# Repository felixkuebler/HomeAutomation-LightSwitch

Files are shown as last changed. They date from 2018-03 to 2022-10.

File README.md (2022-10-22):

# Introduction
Due to the growing demand of iot devices for home automation this project presents an cheap, easy to use and "open source" alternative to brand Products such as Phillips Hue. Based on the ESP8266-12E, a small WiFi enabled chipset, these devices can be retrofitted in a variety of devices such as light switches, motor controllers and more.

Each home automation node will access your local wifi network and is configurable through a webpage hosted locally on the device itsself. Your network needs to provide a [mqtt](https://pagefault.blog/2017/03/02/using-local-mqtt-broker-for-cloud-and-interprocess-communication/) broker to enable communication between nodes thus enabling its full functionality. An easy to use webinterface as well as a mqtt broker is provided by [Openhab](https://www.openhab.org/).

# Light Switch
The light switch module is an small embedded device that can be integrated in your 220 VAC power grid without any special adaptations. Powered by the [HLK-PM01](http://www.hlktech.net/product_detail.php?ProId=54) this module provides two digital inputs as well as two solid state relay outputs. Each input and output can be assigned and modified individually via the local web interface. Due to its small form factor it can easily be fitted behind any flush-mounted box with a min. depth of 41mm.

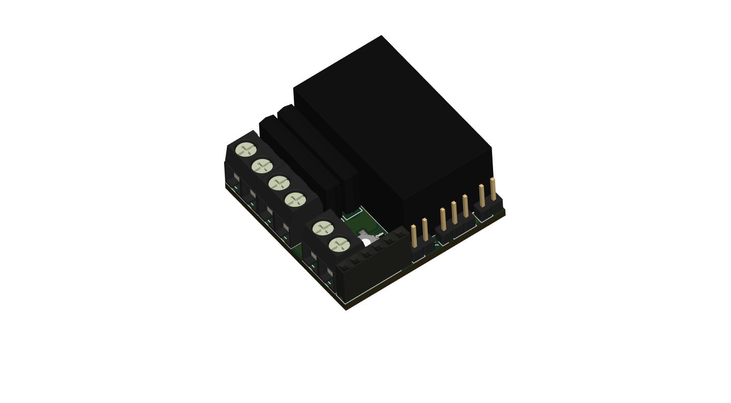
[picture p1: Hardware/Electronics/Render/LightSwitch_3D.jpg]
[light switch render]

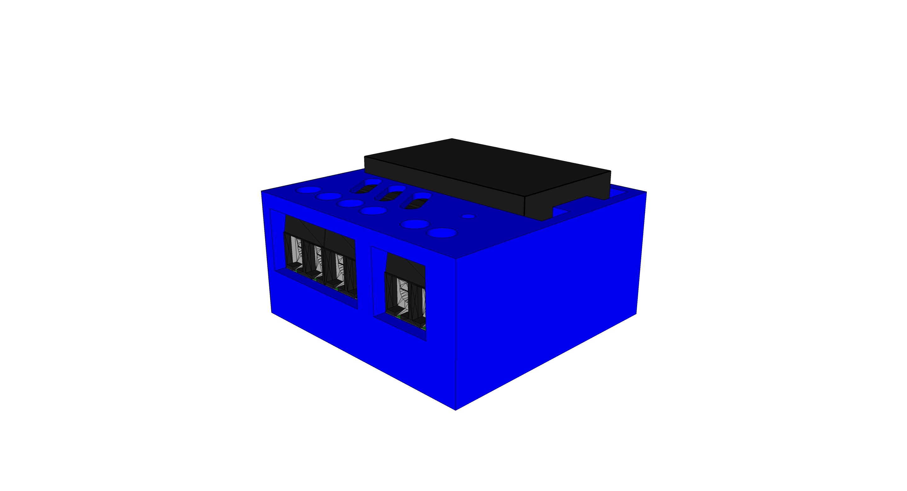
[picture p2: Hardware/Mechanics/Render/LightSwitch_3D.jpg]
[light switch render]


The current versions can be found here:
* [Version 1.0](../../tree/Version1.0)

# License
This work is property of Felix Kübler and is licensed under the
<a rel="license" href="http://creativecommons.org/licenses/by-nc/4.0/">Creative Commons Attribution-NonCommercial 4.0 International License</a>.

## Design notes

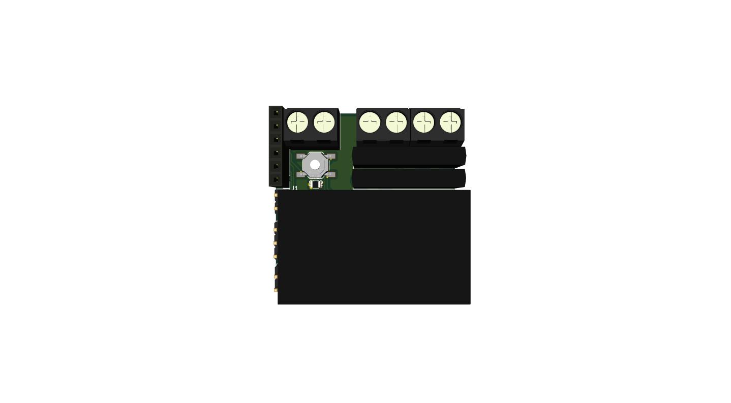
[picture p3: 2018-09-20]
Hardware/Electronics/Render/LightSwitch_top.jpg

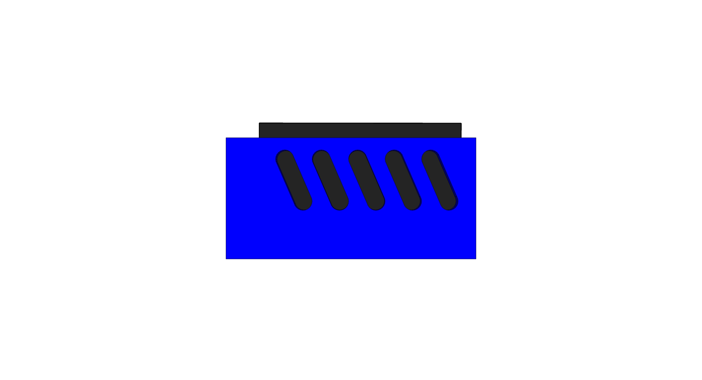
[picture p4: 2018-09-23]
Hardware/Mechanics/Render/LightSwitch_Back.jpg

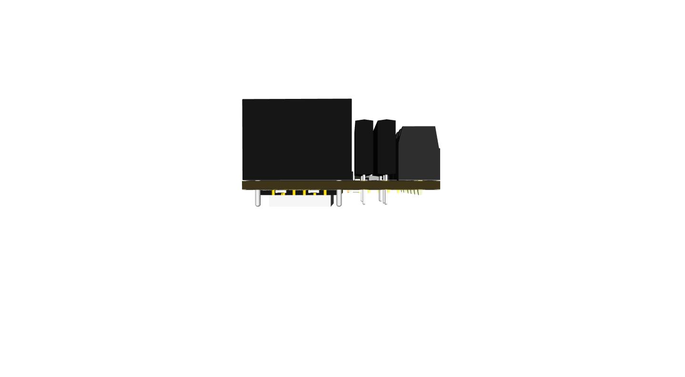
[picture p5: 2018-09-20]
Hardware/Electronics/Render/LightSwitch_right.jpg

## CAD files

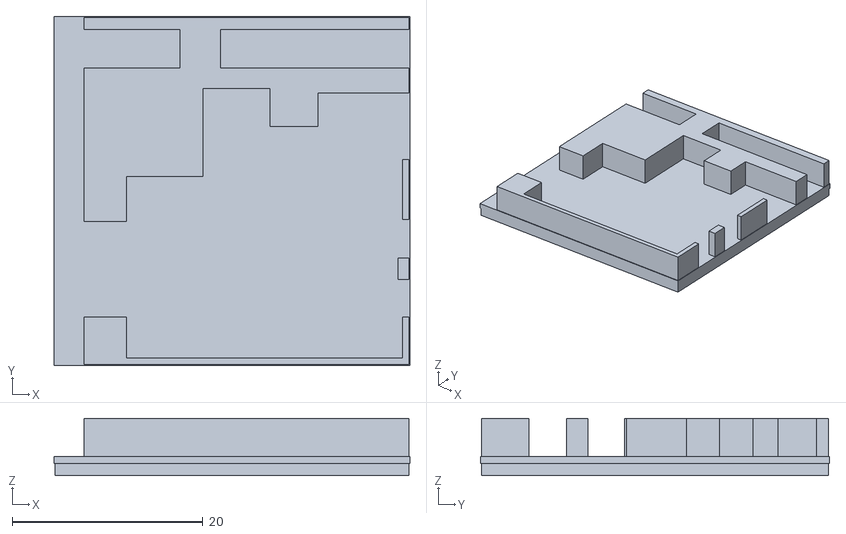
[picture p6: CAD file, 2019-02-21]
Hardware/Mechanics/PrintParts/HousingBottom.stl
37.3 x 36.6 x 6.01

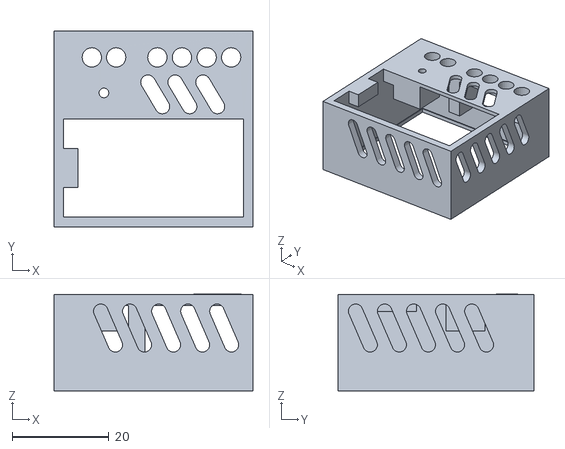
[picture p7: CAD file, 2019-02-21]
Hardware/Mechanics/PrintParts/HousingTop.stl
41.1 x 40.4 x 19.9

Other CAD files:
Hardware/Mechanics/CAD/LightSwitch.skp
Hardware/TestAssembly/CAD/TestAssembly.skp

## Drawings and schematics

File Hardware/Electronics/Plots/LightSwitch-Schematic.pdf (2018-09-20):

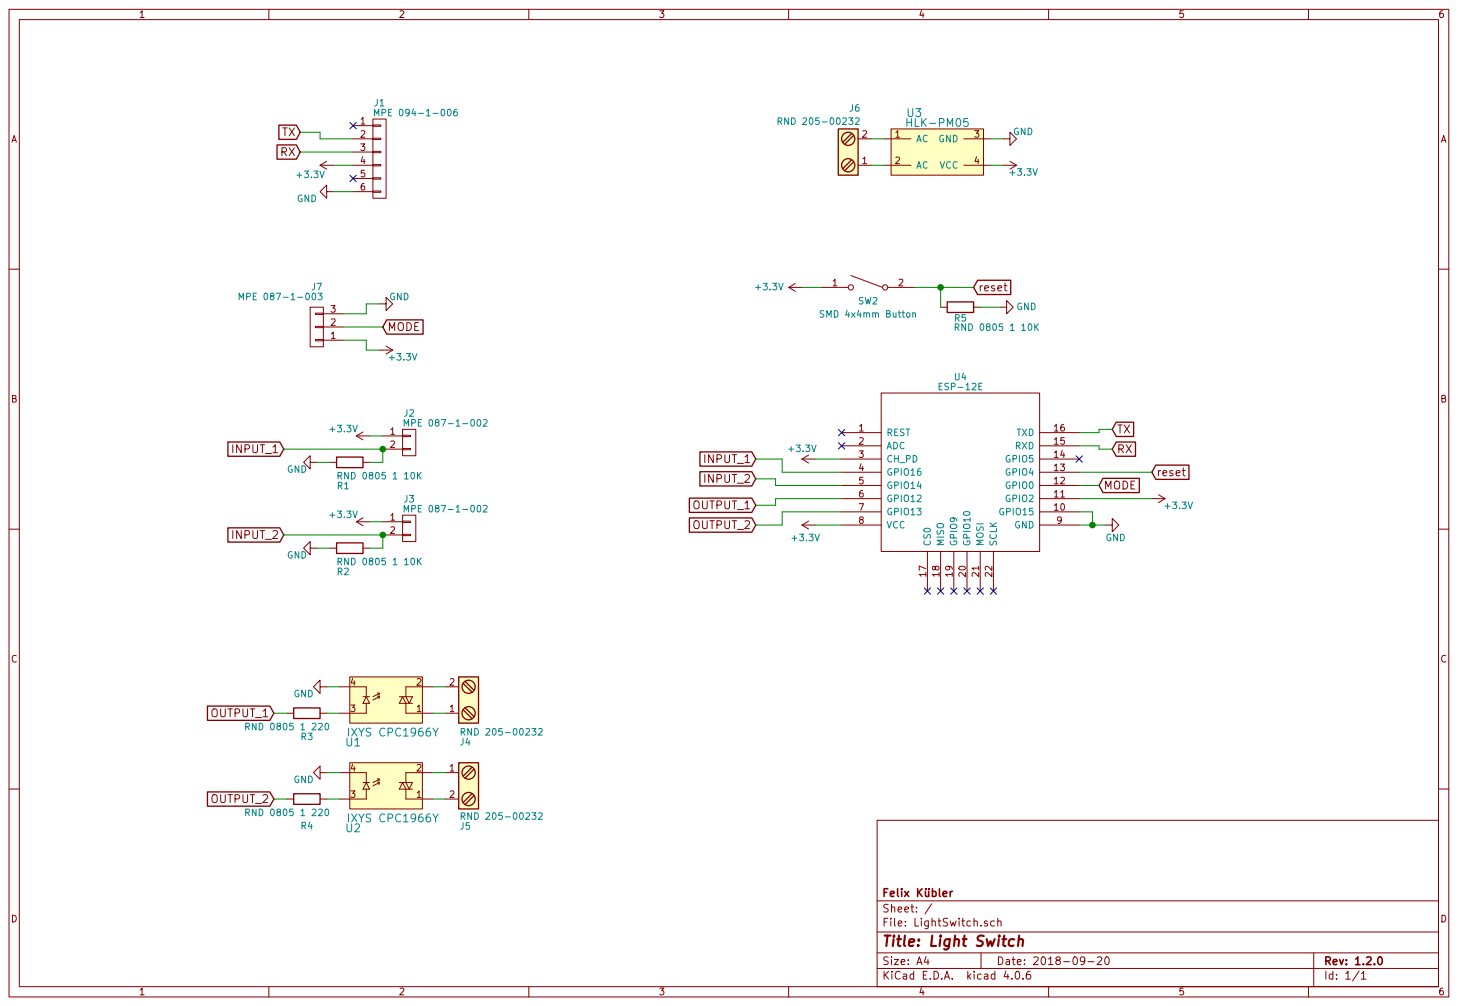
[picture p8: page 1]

File: LightSwitch.sch Sheet: / Felix Kübler

Id: 1/1 Title: Light Switch

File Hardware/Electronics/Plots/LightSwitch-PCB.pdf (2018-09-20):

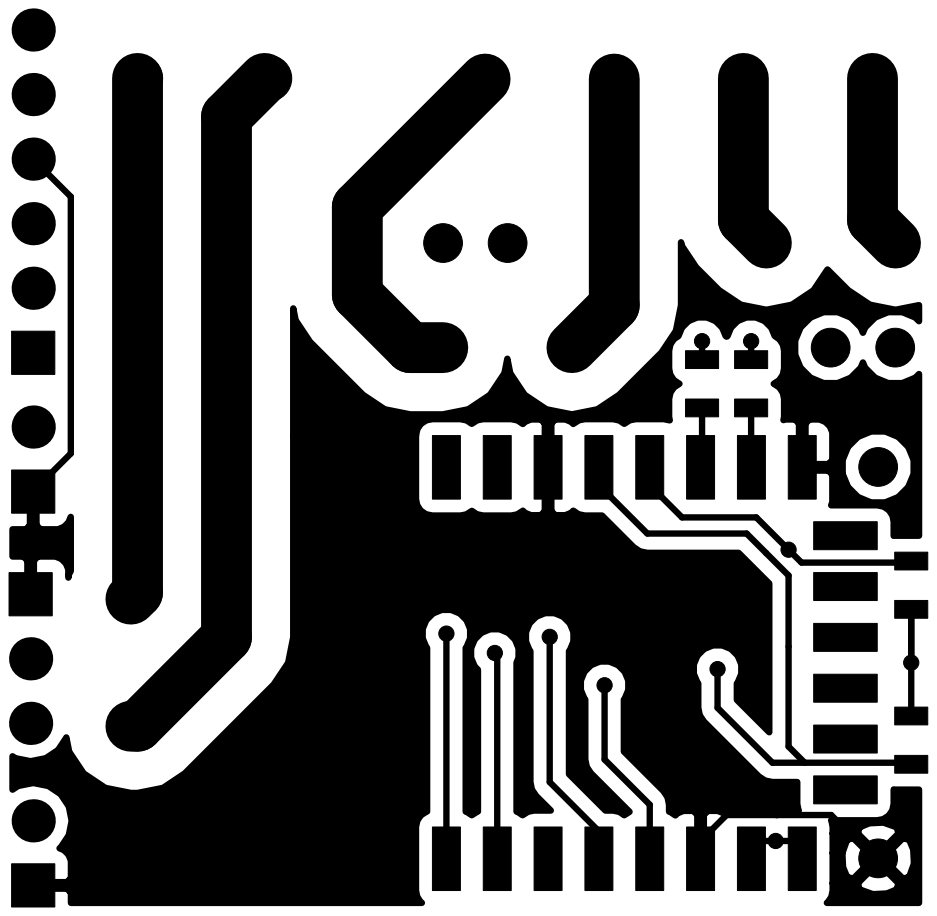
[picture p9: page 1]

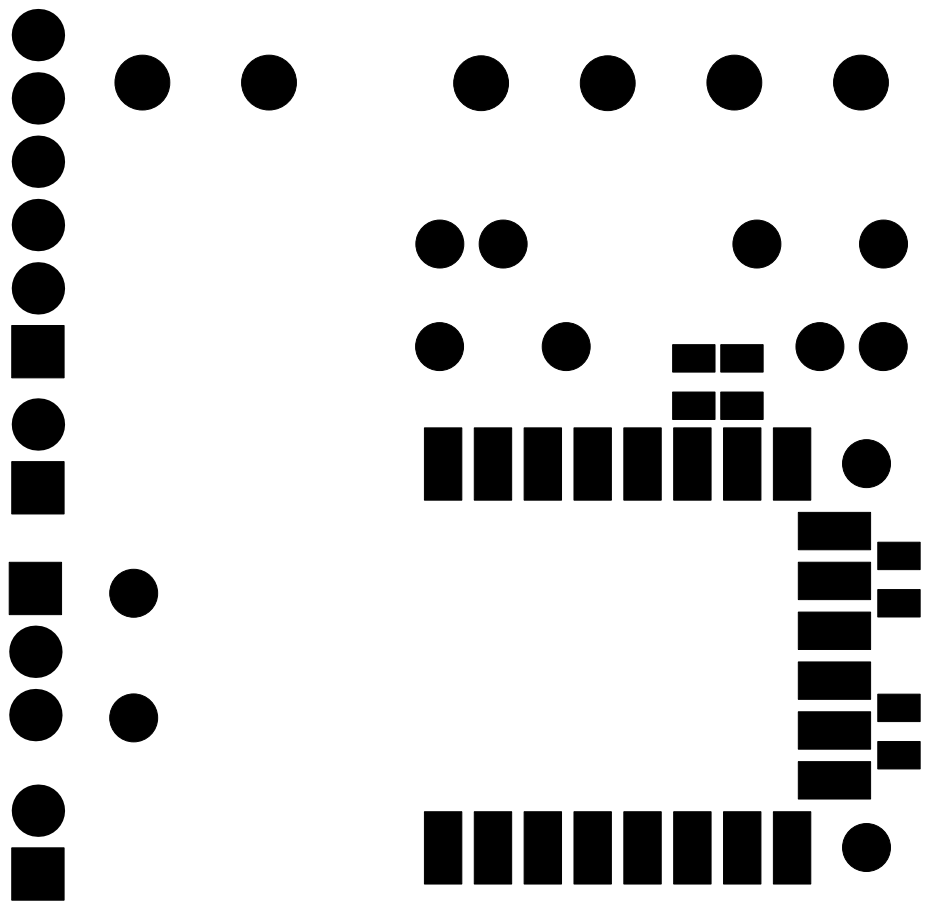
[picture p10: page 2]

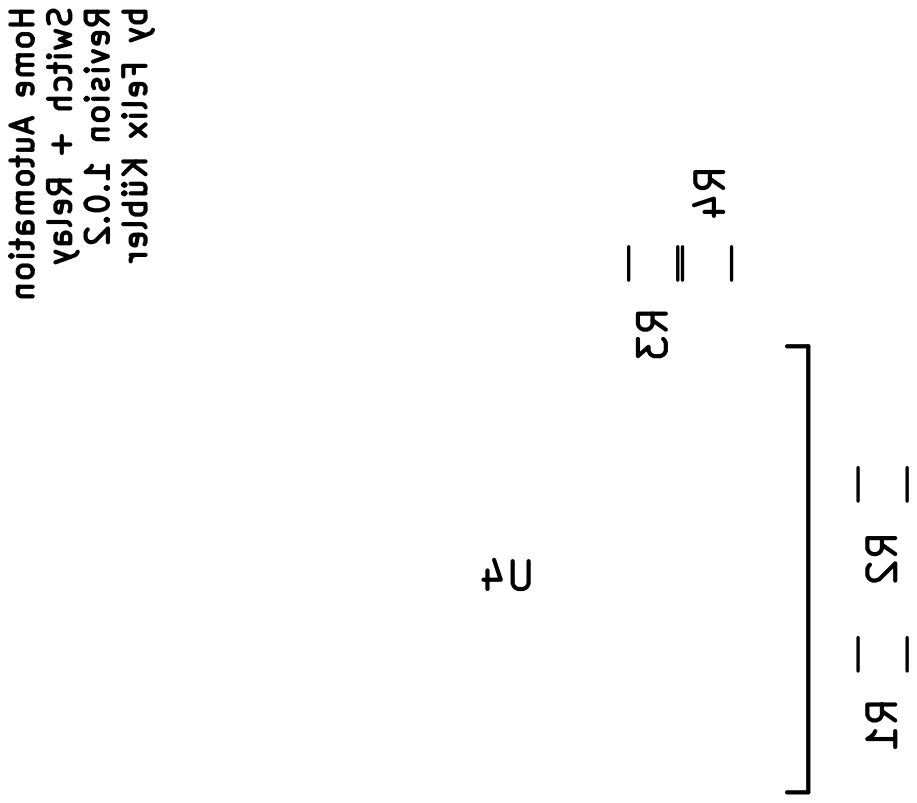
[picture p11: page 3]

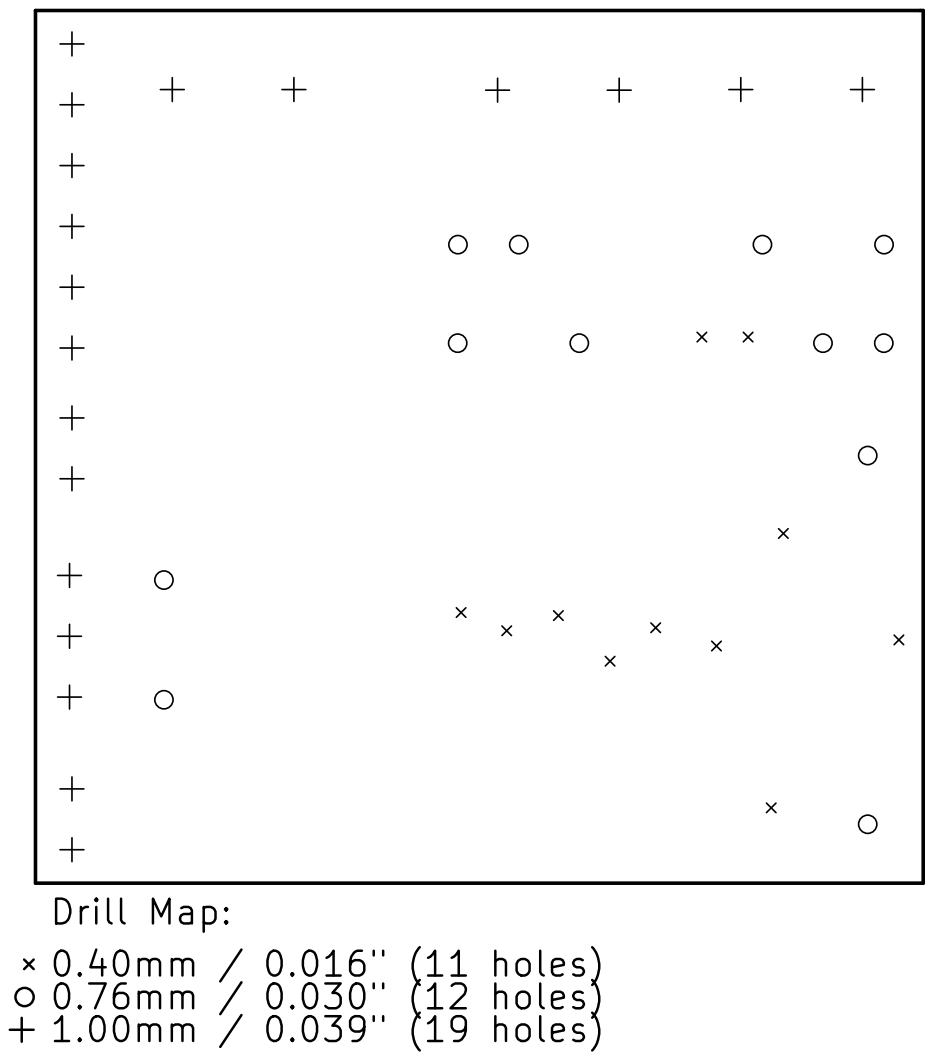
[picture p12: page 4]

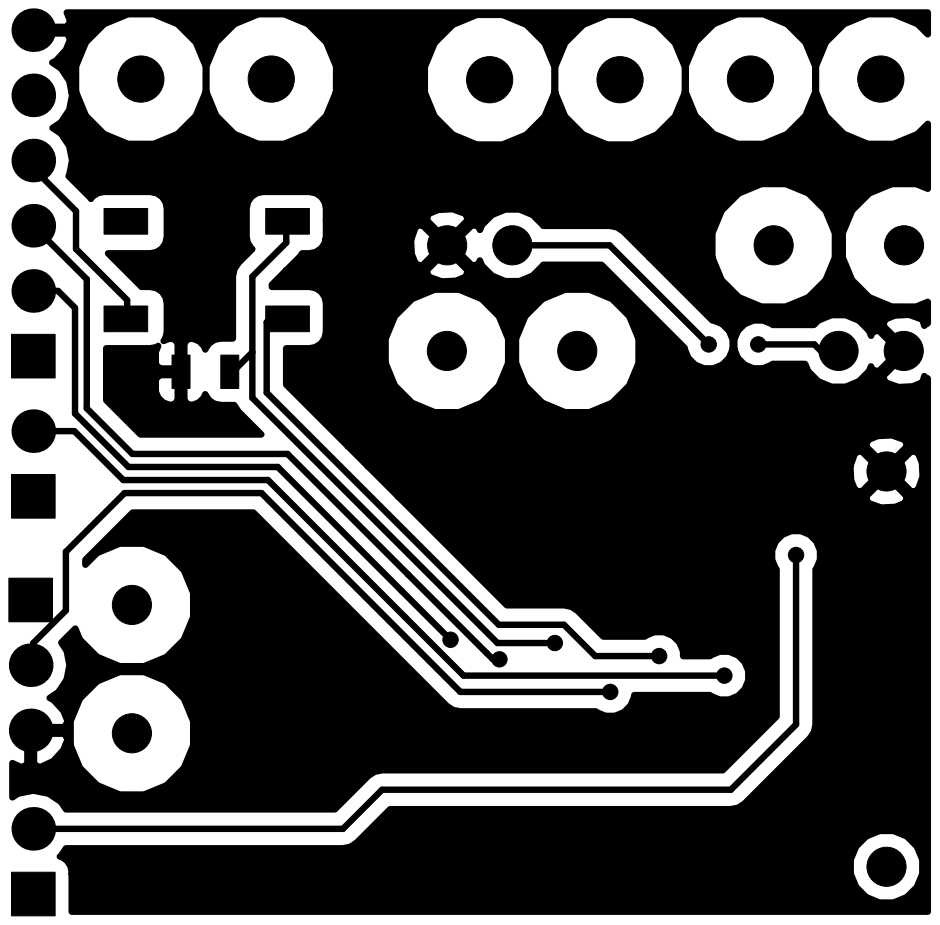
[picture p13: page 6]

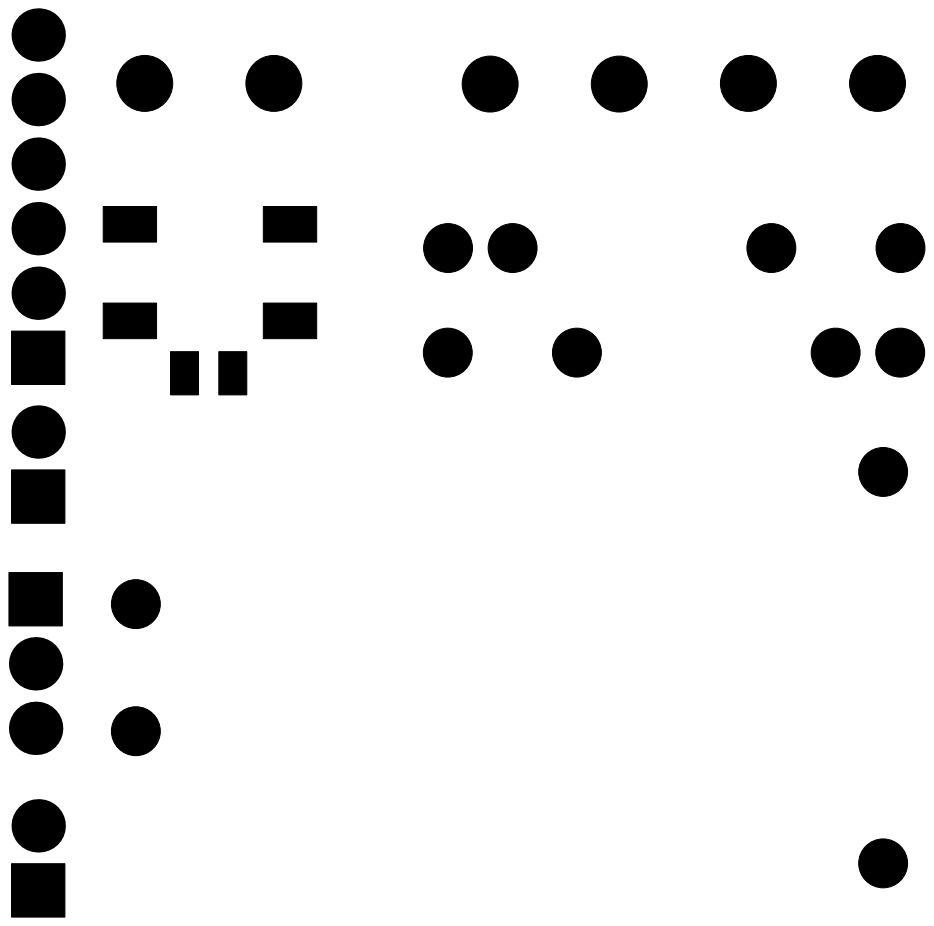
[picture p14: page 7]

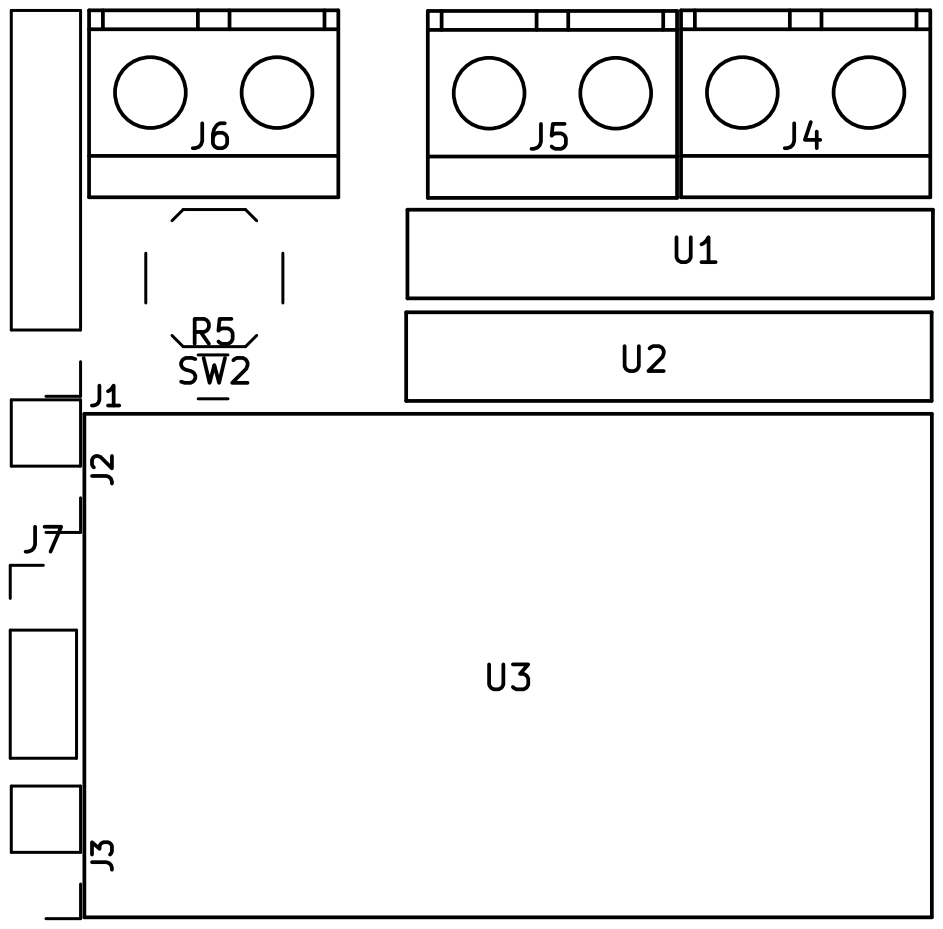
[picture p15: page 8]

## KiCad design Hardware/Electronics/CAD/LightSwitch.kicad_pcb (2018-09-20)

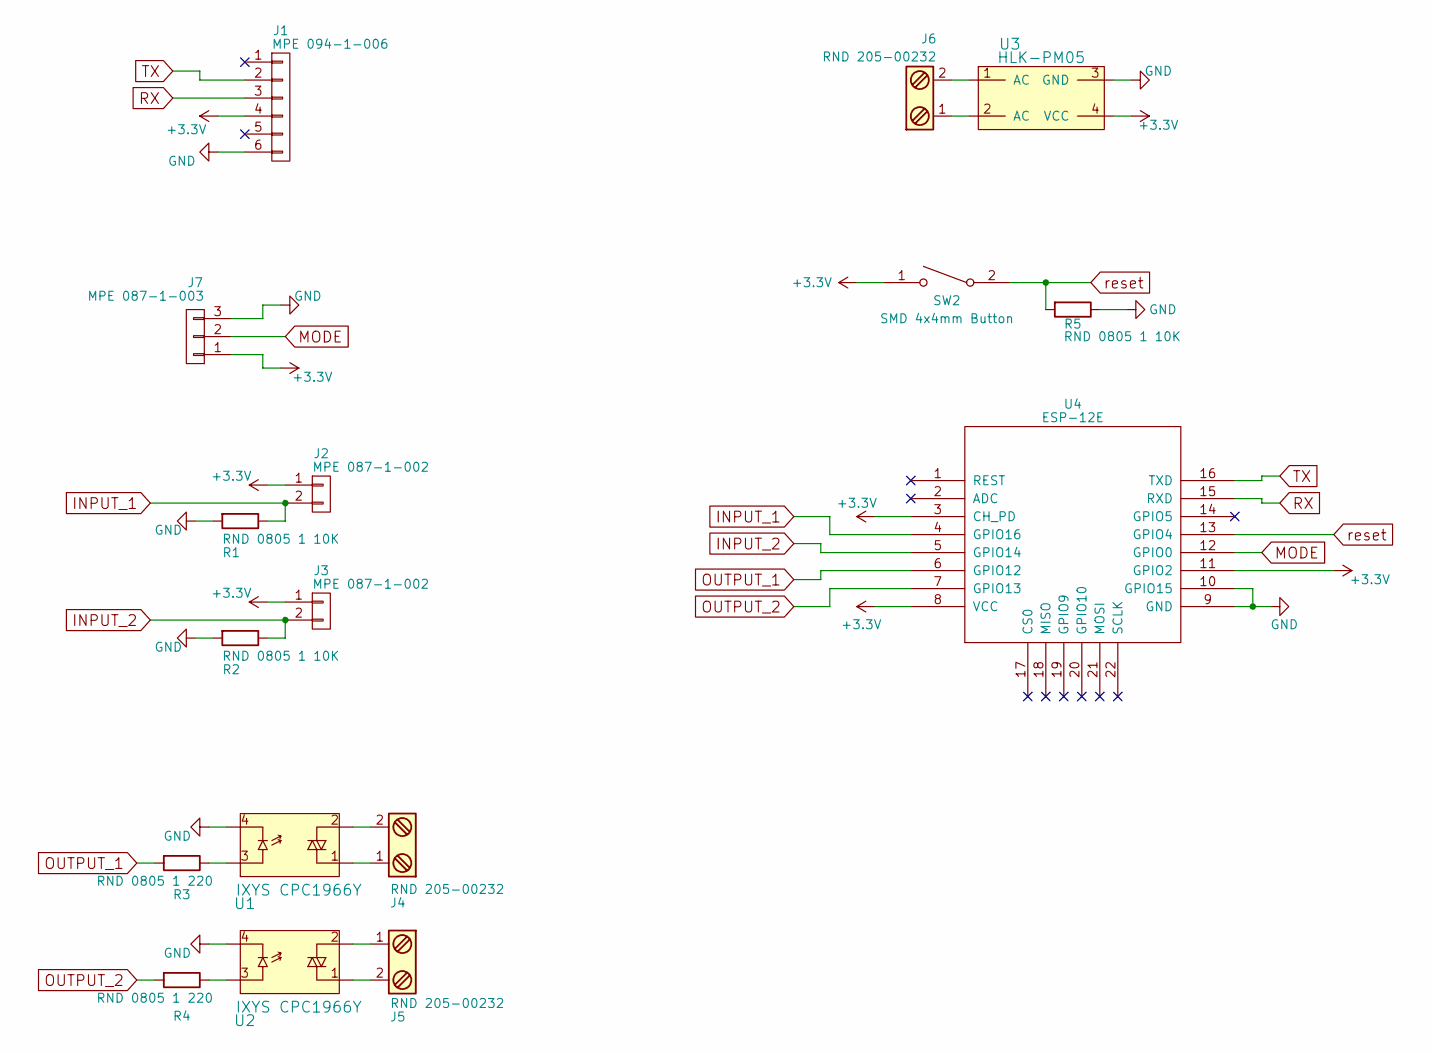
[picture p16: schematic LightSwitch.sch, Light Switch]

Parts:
J1: MPE 094-1-006; Pin_Header_Straight_1x06_Pitch2.54mm
J2, J3: MPE 087-1-002; Pin_Header_Straight_1x02_Pitch2.54mm
J4, J5, J6: RND 205-00232; Terminal_1x2_2.54mm
J7: MPE 087-1-003; Pin_Header_Straight_1x03_Pitch2.54mm
R1, R2, R5: RND 0805 1 10K; R_0805
R3, R4: RND 0805 1 220; R_0805
SW2: SMD 4x4mm Button; SW_SPST_TL3342
U1, U2: IXYS CPC1966Y; CPC1966Y
U3: HLK-PM05; HLK-PM01
U4: ESP-12E; ESP-12E_SMD

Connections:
+3V3: J1.4, J2.1, J3.1, J7.1, SW2.1, U3.4 (VCC), U4.3 (CH_PD), U4.8 (VCC), U4.11 (GPIO2)
GND: J1.6, J7.3, R1.2, R2.2, R5.1, U1.4, U2.4, U3.3 (GND), U4.9 (GND), U4.10 (GPIO15)
INPUT_1: J2.2, R1.1, U4.4 (GPIO16)
INPUT_2: J3.2, R2.1, U4.5 (GPIO14)
MODE: J7.2, U4.12 (GPIO0)
unnamed: J4.1, U1.1
unnamed: J4.2, U1.2
unnamed: J5.1, U2.2
unnamed: J5.2, U2.1
unnamed: J6.1, U3.2 (AC)
unnamed: J6.2, U3.1 (AC)
unnamed: R3.1, U1.3
unnamed: R4.1, U2.3
OUTPUT_1: R3.2, U4.6 (GPIO12)
OUTPUT_2: R4.2, U4.7 (GPIO13)
RX: J1.3, U4.15 (RXD)
TX: J1.2, U4.16 (TXD)
reset: R5.2, SW2.2, U4.13 (GPIO4)

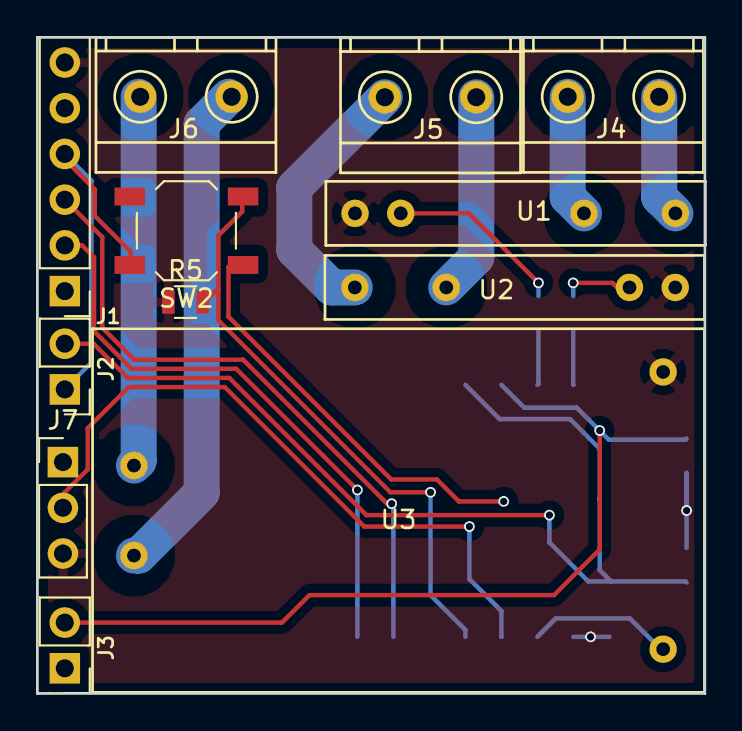
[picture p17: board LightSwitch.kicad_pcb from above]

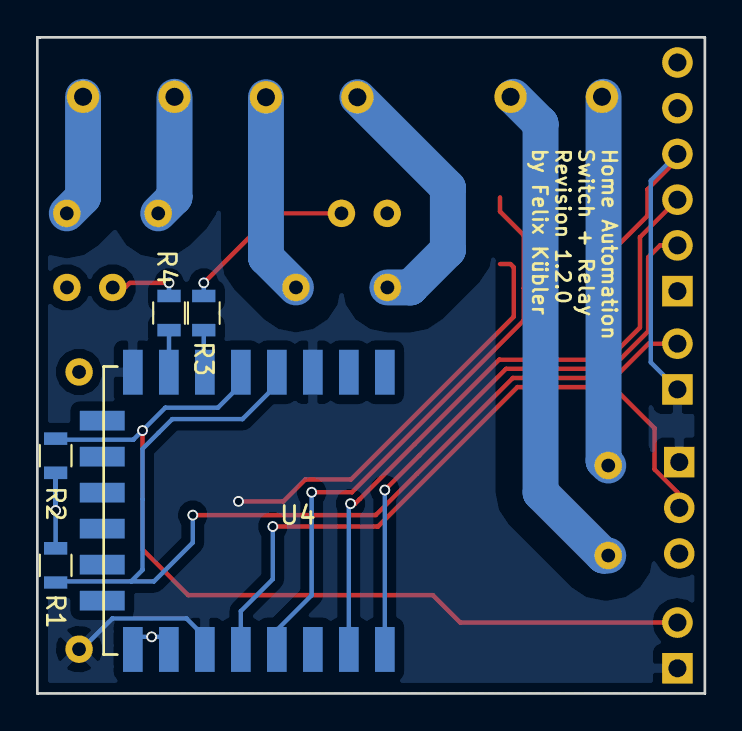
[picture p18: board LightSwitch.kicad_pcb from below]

Board: 2 copper layers, 37.1 x 36.4 mm, 17 parts (5 on the bottom side), 18 nets.

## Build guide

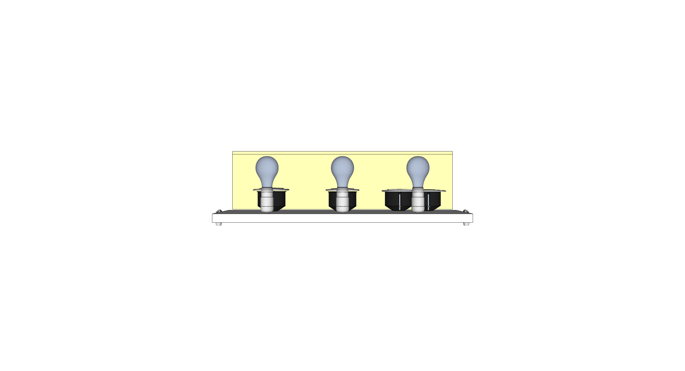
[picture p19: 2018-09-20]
Hardware/TestAssembly/Render/TestAssembly_front.jpg

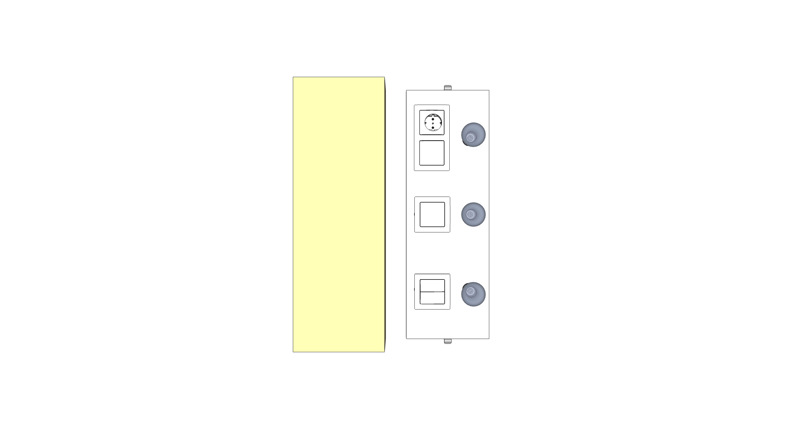
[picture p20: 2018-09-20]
Hardware/TestAssembly/Render/TestAssembly_top.jpg

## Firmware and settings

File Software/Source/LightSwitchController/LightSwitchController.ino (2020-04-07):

/**@file Source.ino**/
 
#include <map>
#include <vector>

#include <ESP8266WiFi.h>
#include <DNSServer.h>
#include <ESP8266WebServer.h>
#include <WiFiClient.h> 
#include <PubSubClient.h>
#include <ESP8266HTTPUpdateServer.h>
#include <EEPROM.h>

#include "utils.h"
#include "io_utils.h"
#include "wifi_utils.h"
#include "eeprom_utils.h"
#include "web_interface.h"


io_list input_list;
io_list output_list;

wifi_obj wifi_info;

short int reset_pin;


DNSServer dnsServer;
ESP8266WebServer wifiServer(80);
WiFiClient wifiClient;
ESP8266HTTPUpdateServer wifiUpdater;
PubSubClient client(wifiClient);


CONFIG setup_type = default_config;
bool network_available = false;



/*
 * this function is called when a html request was send to the local html server
 */
void htmlHandleRequest() 
{

  //webrequest for output
  for (io_list::iterator it=output_list.begin(); it!=output_list.end(); ++it)
  {
    //get name of output
    String val = wifiServer.arg(it->second.topic);
    //check if message is not empty
    if(val.length()>0)
    {
      Serial.print("Setting " + it->second.topic + " to ");

      int trigger_value = -1;
      
      //set changes
      if(strcmp(val.c_str(),"toggle") == 0) 
      {
        if(it->second.state == HIGH)
        {
          trigger_value = LOW;
          Serial.println("OFF");
        }
        else
        {
          trigger_value = HIGH;
          Serial.println("ON");
        }
      }
      else if(strcmp(val.c_str(),"on") == 0) 
      {
        trigger_value = HIGH;
        Serial.println("ON");
      }
      else if(strcmp(val.c_str(),"off") == 0) 
      {
        trigger_value = LOW;
        Serial.println("OFF");
      }


      if(trigger_value != -1)
      { 
        it->second.state = trigger_value;
        digitalWrite(it->second.pin, trigger_value);
      }
    }  
  }
     


  //get ssid request message from client
  String val = wifiServer.arg("wifi_ssid");
  //check if a message is not empty
  if(val.length()>0)
  {
    //set changes
    if(strcmp(val.c_str(),"-1") == 0) val="";
    Serial.println("wifi_ssid : " + val);
    wifi_info.wifi_ssid = val;
  }

  //get pw request message from client
  val = wifiServer.arg("wifi_pw");
  //check if a message is not empty
  if(val.length()>0)
  {
    //set changes
    if(strcmp(val.c_str(),"-1") == 0) val="";
    Serial.println("wifi_pw : " + val);
    wifi_info.wifi_pw = val;
  }

  //get host name request message from client
  val = wifiServer.arg("host_name");
  //check if a message is not empty
  if(val.length()>0)
  {
    //set changes
    if(strcmp(val.c_str(),"-1") == 0) val="";
    Serial.println("host name : " + val);
    wifi_info.host_name = val;
  }

  //get host name request message from client
  val = wifiServer.arg("host_pw");
  //check if a message is not empty
  if(val.length()>0)
  {
    //set changes
    if(strcmp(val.c_str(),"-1") == 0) val="";
    Serial.println("host pw : " + val);
    wifi_info.host_pw = val;
  }
  
  //get mqtt broker request message from client
  val = wifiServer.arg("mqtt_broker");
  //check if a message is not empty
  if(val.length()>0)
  {
    //set changes
    if(strcmp(val.c_str(),"-1") == 0) val="";
    Serial.println("mqtt broker : " + val);
    wifi_info.mqtt_broker = val;
  }
 
  //loop will apply changes to the input settings
  for (io_list::iterator it=input_list.begin(); it!=input_list.end(); ++it)
  {
    //get topic from client
    val = wifiServer.arg(it->first + "_topic");
    //check if message is not empty
    if(val.length()>0)
    {
      if(strcmp(val.c_str(),"-1") == 0) val="";
      Serial.println(it->first + "_topic : " + val);
      //apply changes
      it->second.topic = val;
    }

    //get on command from client
    val = wifiServer.arg(it->first + "_on_command");
    //check if message is not empty
    if(val.length()>0)
    {
      if(strcmp(val.c_str(),"-1") == 0) val="";
      Serial.println(it->first + "_on_command : " + val);
      //apply changes
      it->second.on_command = val;
    }

    //get off command from client
    val = wifiServer.arg(it->first + "_off_command");
    //check if message is not empty
    if(val.length()>0)
    {
      if(strcmp(val.c_str(),"-1") == 0) val="";
      Serial.println(it->first + "_off_command : " + val);
      //apply changes
      it->second.off_command = val;
    }

    //get toggle command from client
    val = wifiServer.arg(it->first + "_toggle_command");
    //check if message is not empty
    if(val.length()>0)
    {
      if(strcmp(val.c_str(),"-1") == 0) val="";
      Serial.println(it->first + "_toggle_command : " + val);
      //apply changes
      it->second.toggle_command = val;
    }
  }

  //loop will apply output changes
  for (io_list::iterator it=output_list.begin(); it!=output_list.end(); ++it)
  {
    //get topic from client
    val = wifiServer.arg(it->first + "_topic");
    //check if message is not empty
    if(val.length()>0)
    {
      if(strcmp(val.c_str(),"-1") == 0) val="";
      Serial.println(it->first + "_topic : " + val);
      //apply changes
      it->second.topic = val;
    }

    //get on command from client
    val = wifiServer.arg(it->first + "_on_command");
    //check if message is not empty
    if(val.length()>0)
    {
      if(strcmp(val.c_str(),"-1") == 0) val="";
      Serial.println(it->first + "_on_command : " + val);
      //apply changes
      it->second.on_command = val;
    }

    //get off command from client
    val = wifiServer.arg(it->first + "_off_command");
    //check if message is not empty
    if(val.length()>0)
    {
      if(strcmp(val.c_str(),"-1") == 0) val="";
      Serial.println(it->first + "_off_command : " + val);
      //apply changes
      it->second.off_command = val;
    }

    //get toggle command from client
    val = wifiServer.arg(it->first + "_toggle_command");
    //check if message is not empty
    if(val.length()>0)
    {
      if(strcmp(val.c_str(),"-1") == 0) val="";
      Serial.println(it->first + "_toggle_command : " + val);
      //apply changes
      it->second.toggle_command = val;
    }
  }

  //get reset trigger from client
  String reset_settings = wifiServer.arg("reset_settings");
  //check if a reset was triggered
  if(reset_settings.length()>0)
  {
    Serial.println("System Settings set to default");
    //write reset flag to eeprom to use after a system reboot
    saveResetByteToEEPROM(0);

    //reboot system
    ESP.eraseConfig();
    ESP.reset();
  }

  //get save trigger from client
  String save_settings = wifiServer.arg("save_settings");
  //check if save was triggered
  if(save_settings.length()>0)
  {
    Serial.println("user settings saved, system is going to restart");

    //save local changes to eeprom
    saveSettingsToEEPROM(wifi_info, input_list, output_list);
    saveResetByteToEEPROM(1);
    
    //reboot system
    ESP.eraseConfig();
    ESP.reset();
  }

  //give wifiServer new webpage
  wifiServer.send(200, "text/html", generateWebpage(wifi_info, input_list, output_list));
}


/*
 * this function is called when a mqtt post was received
 */
void mqttSubscribeCallback(char* topic, byte* payload, unsigned int length) 
{  
  //loop through all available outputs
  for (io_list::iterator it=output_list.begin(); it!=output_list.end(); ++it)
  {
    //check if subscribe topic is equal to output topic
    if (strcmp(topic,(it->second.topic).c_str())==0)
    {
      //turn byte* into String
      String msg ="";
      for(int i=0; i<length; i++)
      {
        msg+=(char)payload[i];
      }

      Serial.print("mqtt post \"");
      Serial.print(msg);
      Serial.print("\" on topic \"");
      Serial.print(topic);
      Serial.println("\" received");
  
      short int trigger_value = -1;
      
      if(it->second.on_command.length()>0 && strcmp(msg.c_str(),it->second.on_command.c_str())==0)
      {
        trigger_value = 1;
      }
      else if(it->second.off_command.length()>0 && strcmp(msg.c_str(),it->second.off_command.c_str())==0)
      {
        trigger_value = 0;
      }
      else if(it->second.toggle_command.length()>0 && strcmp(msg.c_str(),it->second.toggle_command.c_str())==0)
      {
        if (it->second.state == 0)
        {
          trigger_value = 1;
        }
        else 
        {
          trigger_value = 0;
        }
      }

      if(trigger_value != -1)
      {
        //write value to pin
        Serial.print("set ");
        Serial.print(it->first);
        Serial.print(" to ");
        Serial.println(trigger_value);
      
        it->second.state = trigger_value;
        digitalWrite(it->second.pin, trigger_value);
      }
      else
      {
        Serial.print("unknown command");
      }
    }
  }
}

/*
 * this function is called a interrupt was triggerd on an input pin
 */
void mqttPublishCallback() 
{  
  //loop through inputs
  for (io_list::iterator it=input_list.begin(); it!=input_list.end(); ++it)
  {
    //reade current state from pin
    short int state = digitalRead(it->second.pin);
    //compare to last known state
    if(state!=it->second.state)
    {
      //change to new state
      it->second.state=state;
      
      //write value to pin
      Serial.print("io input triggered by ");
      Serial.println(it->first);

      if(it->second.on_command.length()>0 && state==HIGH)
      {
        Serial.print("post \"");
        Serial.print(it->second.on_command);
        Serial.print("\" on topic \"");
        Serial.print(it->second.topic);
        Serial.println("\"");
        //publish on command to pin topic
        client.publish((it->second.topic).c_str(), (it->second.on_command).c_str());
      }

      if(it->second.off_command.length()>0 && state==LOW)
      {
        Serial.print("post \"");
        Serial.print(it->second.off_command);
        Serial.print("\" on topic \"");
        Serial.print(it->second.topic);
        Serial.println("\"");
        //publish off command to pin topic
        client.publish((it->second.topic).c_str(), (it->second.off_command).c_str());
      }

      if(it->second.toggle_command.length()>0)
      {
        Serial.print("post \"");
        Serial.print(it->second.toggle_command);
        Serial.print("\" on topic \"");
        Serial.print(it->second.topic);
        Serial.println("\"");
        //publish toggle command to pin topic
        client.publish((it->second.topic).c_str(), (it->second.toggle_command).c_str());
      }
    }
  }
}

/*
 * this function tryes to reconnect the mqtt client to the mqtt broker
 */
void mqttReconnect() 
{
  //repeat until a connection is astablished
  if (!client.connected()) 
  {
    Serial.print("attempting mqtt connection to ");
    Serial.print(wifi_info.mqtt_broker);
    Serial.print(" as ");
    Serial.print(wifi_info.host_name);
    Serial.print("...");
    
    // attempt to connect
    if (client.connect(wifi_info.host_name.c_str()))
    {
      Serial.println("  ok");

      //setup subscribe topics for relays
      for (io_list::iterator it=output_list.begin(); it!=output_list.end(); ++it)
      {
        //add ouputs to mqtt subscriber list
        client.subscribe((it->second.topic).c_str());
      }
    } 
    else 
    {
      //print error value
      Serial.print("  fail, rc=");
      Serial.println(client.state());
    }
  }
}


/*
 * this function will setup all wifi functions
 */
void wifi_setup(char reset_byte)
{
  //check reset indicatior
  if(reset_byte==0)
  {
    //reset was applied
    Serial.println("0  -> reset to default config");
    
    //save default settings to eeprom
    Serial.println("save default settings to epprom");
    Serial.print(wifiToString(wifi_info));
    Serial.print(ioListToString(input_list));
    Serial.print(ioListToString(output_list));
    saveSettingsToEEPROM(wifi_info, input_list, output_list);

    //start access point for settings configuration 
    Serial.println("start access point");
    WiFi.softAPdisconnect(true);
    WiFi.disconnect();
    WiFi.mode(WIFI_AP);
    delay(100);
    WiFi.hostname(wifi_info.host_name);
    WiFi.softAPConfig(IPAddress(192, 168, 1, 1), IPAddress(192, 168, 1, 1), IPAddress(255, 255, 255, 0));
    WiFi.softAP(wifi_info.host_name.c_str());

    Serial.println("start dns captive portal");
    dnsServer.start(53, "*", IPAddress(192, 168, 1, 1));

    setup_type = default_config;
  }
  else
  {
    //reset was not applied
    Serial.println("1  -> load user config");

    //load settings from eeprom, make backup of wifi_info
    Serial.println("load settings from epprom");
    wifi_obj wifi_info_backup = wifi_info;
    loadSettingsFromEEPROM(wifi_info, input_list, output_list);
    Serial.print(wifiToString(wifi_info));
    Serial.print(ioListToString(input_list));
    Serial.print(ioListToString(output_list));
    
    //connect to wifi network
    Serial.println("start as wifi client station");
    WiFi.softAPdisconnect(true);
    WiFi.disconnect();
    WiFi.mode(WIFI_STA);
    delay(100);
    WiFi.hostname(wifi_info.host_name);

    if(wifi_info.wifi_pw.length()>0)
    {
      WiFi.begin(wifi_info.wifi_ssid.c_str(), wifi_info.wifi_pw.c_str());
    }
    else
    {
      WiFi.begin(wifi_info.wifi_ssid.c_str());
    }

    //wait for wifinetwork, timeout after 20 seconds
    Serial.print("connecting to ");
    Serial.print(wifi_info.wifi_ssid);
    Serial.print("...");
    bool timeout = false;
    for(int timer = 0; WiFi.status() != WL_CONNECTED; timer++)
    {
      delay(500);
      Serial.print(".");

      if(timer>=40)
      {
        timeout = true;
        break;
      }
    }

    //check if timeout occured
    if(timeout)
    {
      //timeout was triggered
      Serial.println(" fail");
      
      //start access point if connection to network not possible
      Serial.println("start as accesspoint");
      WiFi.softAPdisconnect(true);
      WiFi.disconnect();
      WiFi.mode(WIFI_AP);
      delay(100);
      WiFi.hostname(wifi_info.host_name);
      WiFi.softAPConfig(IPAddress(192, 168, 1, 1), IPAddress(192, 168, 1, 1), IPAddress(255, 255, 255, 0));

      if(wifi_info.host_pw.length()>0)
      {
        WiFi.softAP(wifi_info.host_name.c_str(), wifi_info.host_pw.c_str());
      }
      else
      {
        WiFi.softAP(wifi_info.host_name.c_str());
      }

      Serial.println("start dns captive portal");
      dnsServer.start(53, "*", IPAddress(192, 168, 1, 1));

      setup_type=backup_config;

      network_available = networkAvailable(wifi_info.wifi_ssid);

    }
    else 
    {
      //no timeout
      Serial.println(" ok");

      //start mqtt client
      Serial.println("start mqtt pub/sub client");
      client.setServer(wifi_info.mqtt_broker.c_str(), 1883);
      client.setCallback(mqttSubscribeCallback);

      setup_type = user_config;
    }
  }
    
  //define request actions
  wifiServer.onNotFound(htmlHandleRequest);

  //start http server
  Serial.println("start http server");
  wifiUpdater.setup(&wifiServer);
  wifiServer.begin();
}


/*
 * on system boot this function is called once for setup purposes
 */
void setup(void)
{
  //start serial connection
  Serial.begin(9600);

  //add switches with default values
  addToIOList(input_list, "switch_1", "switch_1", 16, INPUT);
  addToIOList(input_list, "switch_2", "switch_2", 14, INPUT);

  //add relays with default values
  addToIOList(output_list, "relay_1", "relay_1", 12, OUTPUT);
  addToIOList(output_list, "relay_2", "relay_2", 13, OUTPUT);

  //add default wifi info
  wifi_info = wifi_obj("Andre_Test_Switch");

  reset_pin = 4;

  //define eeprom space
  EEPROM.begin(512);

  //read first byte of eeprom as reset indicatior
  Serial.print("read reset byte from eeprom: ");
  char reset_byte;
  readResetByteFromEEPROM(reset_byte);
  
  wifi_setup(reset_byte);
}


/*
 * main loop that evaluates dns, wifiServer and mqtt events
 */
void loop(void)
{
  //check if a connection to network was established
  if(setup_type==user_config)
  {
    //try to connect to mqtt broker
    mqttReconnect();

    //if connection lost reboot
    if(WiFi.status() != WL_CONNECTED)
    {
      WiFi.softAPdisconnect(true);
      WiFi.disconnect();
      delay(100);
      wifi_setup(1);
    }
  }
  else if(setup_type==backup_config)
  {
    //check if a network exists that matches the users network that did not exist before
    if(!network_available)
    {
      if(networkAvailable(wifi_info.wifi_ssid))
      {
        WiFi.softAPdisconnect(true);
        WiFi.disconnect();
        delay(100);
        wifi_setup(1);
      }
    }
  }

  //repeat following commands 100 times before next mqtt reconnect attempt
  for (short int timeout = 0; timeout < 100; timeout++)
  { 
    //check if a connection to network was established
    if(setup_type==user_config)
    {
      //handle mqtt client
      client.loop();
      mqttPublishCallback();
    }

    dnsServer.processNextRequest();
    wifiServer.handleClient();

    delay(50);
  }

  //check for hardware reset
  if(digitalRead(reset_pin)==HIGH)
  {
    /*
    Serial.print("reset button high");
    writeCharToEEPROM(0, 0);
    ESP.eraseConfig();
    ESP.reset();
    */
  }
}

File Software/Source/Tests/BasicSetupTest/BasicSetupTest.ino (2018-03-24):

#define switch1 16
#define switch2 14
#define relay1  12
#define relay2  13

void setup(void)
{
  
  pinMode(switch1, INPUT);
  pinMode(switch2, INPUT);

  pinMode(relay1, OUTPUT);
  pinMode(relay2, OUTPUT);

}

void loop(void)
{
  delay(10);
}

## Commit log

2018-02-15 light switch single repo setup
    [BeltMountNoTeeth.stl, BeltMountSupport.stl, BeltMountTeeth.stl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]
2018-02-18 updated files
    [BeltMountNoTeeth.stl, BeltMountSupport.stl, BeltMountTeeth.stl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]
2018-04-08 kicad linkage fix
2018-04-15 3d model improvement and default parts
    [LightSwitch.kicad_pcb, LightSwitch.sch]
2018-09-03 test assembly
    [TestAssembly.skp]
2018-09-03 library linkage fix
    [LightSwitch.kicad_pcb, LightSwitch.sch]
2018-09-05 terminal footprints
    [LightSwitch.kicad_pcb, LightSwitch.sch]
2018-09-23 housing for pcb
    [HousingBottom.stl, HousingTop.stl]
2019-02-21 housing concept
    [HousingBottom.stl, HousingTop.stl]
